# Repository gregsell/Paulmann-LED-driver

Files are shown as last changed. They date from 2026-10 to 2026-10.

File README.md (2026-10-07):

# Dimmable LED driver analysis
The situation: I bought several LED spots called "Nova Plus" by the company Paulmann.   
(https://de.paulmann.com/p/led-modul-einbauleuchte-nova-plus-coin-rund-50mm-coin-6w-470lm-230v-dimmbar-2700k-satin/93078)

The lights are rated for 6W and intended for use with a dimmer, but many of them stopped working. Time for investigations.

## Driver PCB

Main goal: create schematic from scratch and understand how things work. Ideally fix the broken units.  
The IC is a `iW3688` by Renesas. It supports leading and trailing edge dimming. The `-01` variant found here supports 230VAC input with up to 14 W output power.  
(https://www.renesas.com/en/document/prb/iw3688-product-summary?r=1543101)

For most defective units the only apparent damage was the blown fusible resistor. All the other simple components seemed fine.  
The state of the main IC could not be assessed due to lack of information and tooling.

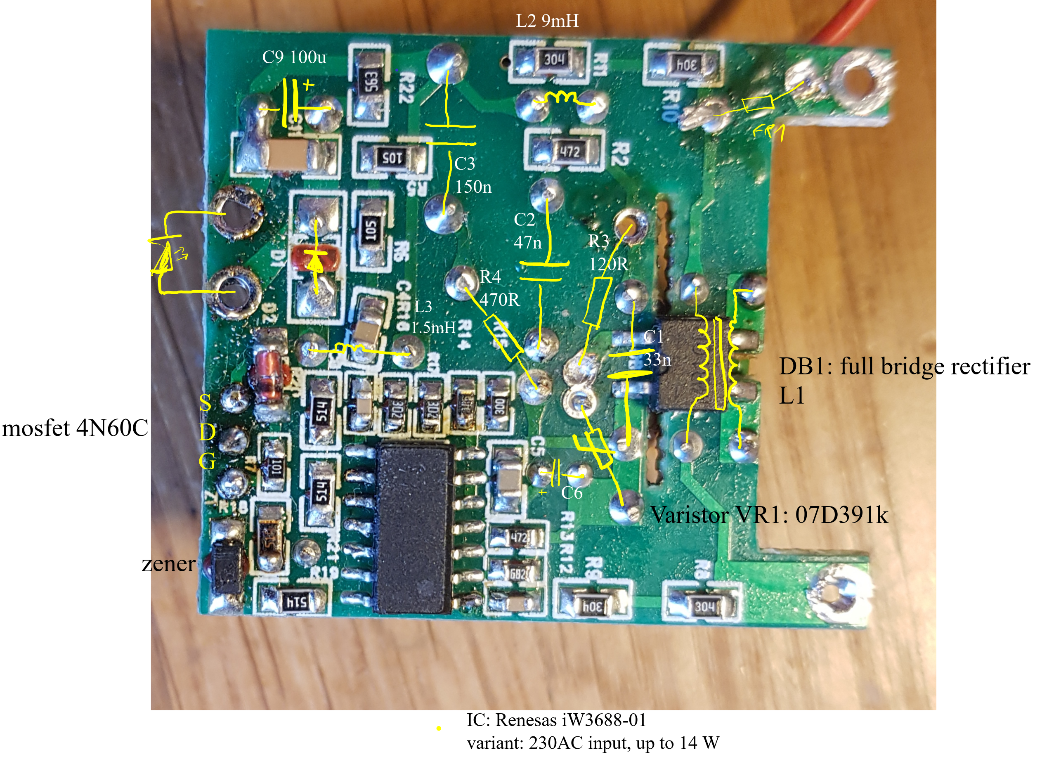
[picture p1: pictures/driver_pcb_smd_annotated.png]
driver pcb smd annotated

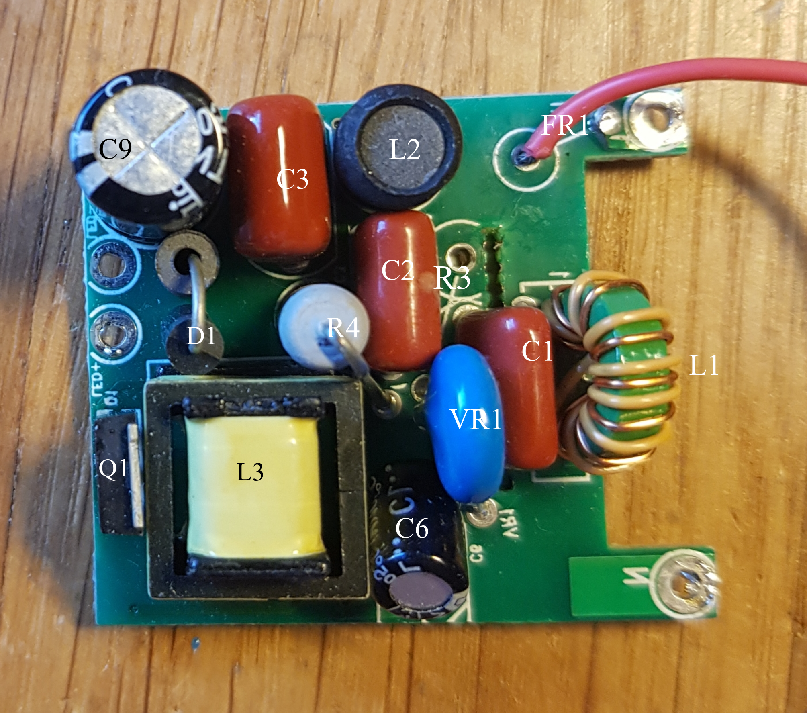
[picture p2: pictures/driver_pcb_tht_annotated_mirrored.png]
driver pcb tht annotated
  
(mirrored)

### Schematic

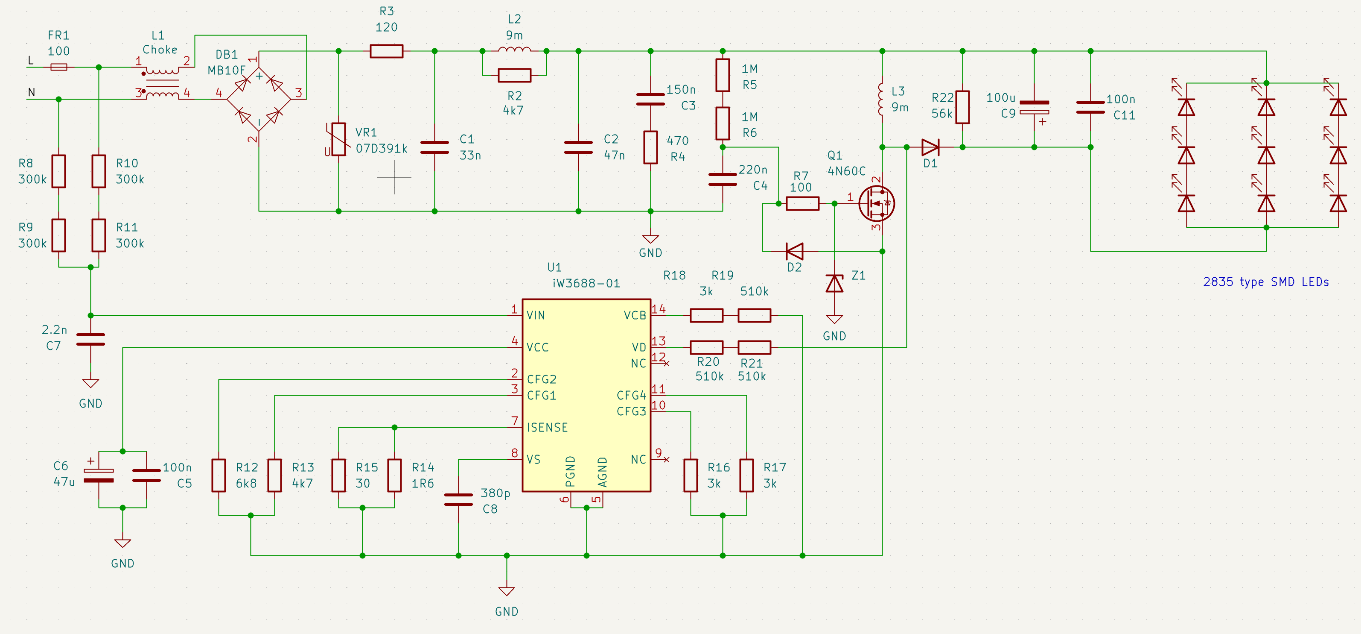
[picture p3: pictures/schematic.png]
reverse engineered schematic


The schematic turned out to be very similar to the example in the production summary.

## Failure analysis
TBD  

## LED PCB

The seperate pcb with the actual LEDs contains 15 SMD LEDs in total. Five strings of each 3 LEDs in series.  
The package form is 2835 (2,8 x 3,5mm).
While 'usual' white LEDs work in the ~3V range these turn on at about 15 V.

None of the defective units had failed LEDs. Assuming a single SMD LED failed, the two remaining strings will be loaded 50 % more and soon overheat. This is due to the constant-current driving mechanism of LED drivers. 

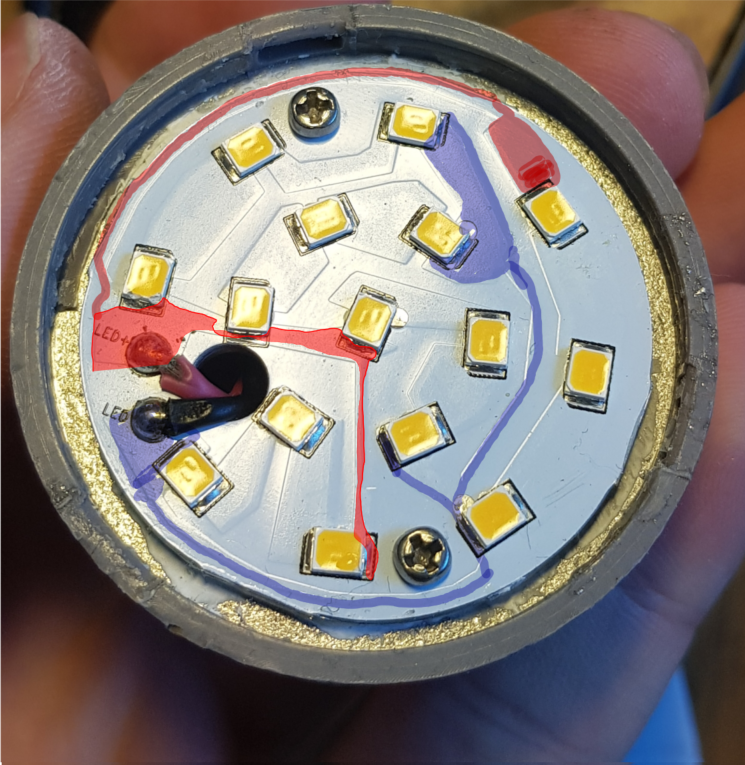
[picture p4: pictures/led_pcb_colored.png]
led pcb colored traces


## Extending LED lifetime

It is common for LED drivers to 'push' too much current through the LEDs. As a result they get hot and the lifetime shortens. For many (cheap) lights this is a very common failure mode.  
In this case though the LEDs are still working. Nevertheless, investigating how to modify the drivers behaviour is at least interesting.

The used IC has several resistors for configuring behaviour, one of them ($R_{14} || R_{15}$) is used to set the current to power the LEDs ($I_{LED}$) 

In the table below are measurements comparing the stock configuration with a modified one.
- $U_{LED}$:    Average DC voltage measured across LEDs
- $I_{LED}$:    Average DC current flowing through LEDs
- $R_{sense}$:  Resistor for defining $I_{LED}$. It is consists of $R_{14}$ and $R_{15}$ in parallel

| | $U_{LED}$ [V] |  $I_{LED}$ [mA] | $R_{sense}$ [Ohm] |
| --- | --- | --- | --- |
| stock | 52 | 101 | 1,5 |
| mod | 50 | 50 | 3,1 |

Therefore the correlation  $I_{LED} \propto 1/R_{sense} $  holds. This is common for LED drivers.

## Possible further investigations
Unfortunately a full datasheet of the `iW3688` IC by Renesas is not available, only [this production summary](https://www.renesas.com/en/document/prb/iw3688-product-summary?r=1543101). Thus further analysis is hardly possible. 

### Precise measurement of $U_{LED}$

All measurements above were done with a simple digital multimeter (DMM).  
Probing the output voltage relative to earth with an oscilloscope led to the following graph:    

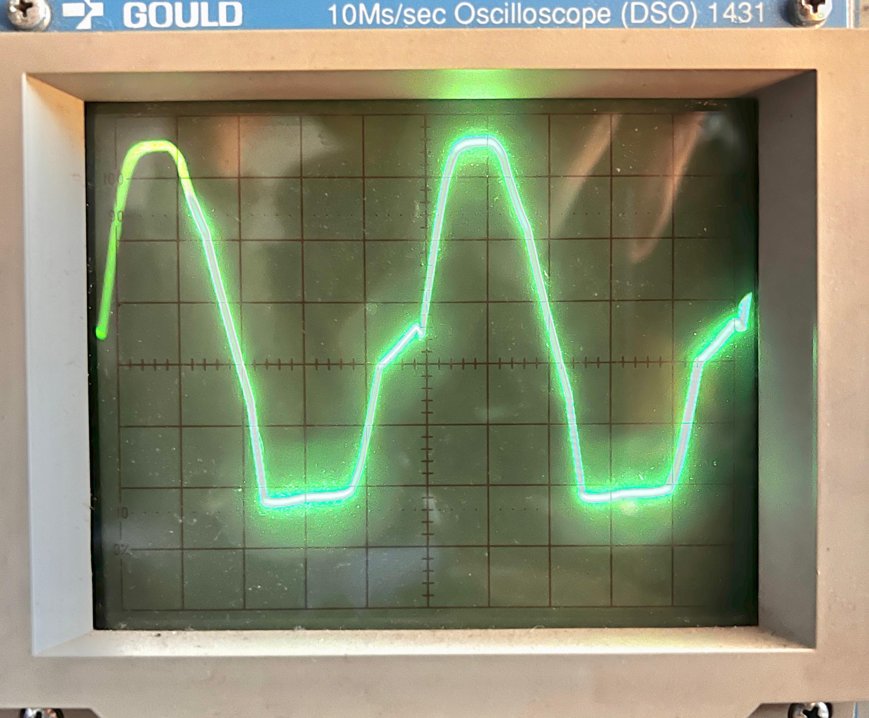
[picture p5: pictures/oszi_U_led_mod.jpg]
U_led on oscilloscope (R_sense modified)


Zero volts reference is at the bottom of the screen.
The units are:
- 20 V / div. vertically
- 20 ms / div. horizontally  

#### Observations:
The base frequency is 50 Hz, although for a full bridge rectifier it should be double that.

#### Why this measurement was not very useful:
Neither do I own an isolation transformer nor differential probes. Thus the point of reference (neg. LED terminal) (might be?) swinging as well. *I think* this could be solved by using a second probe (which I do not have) and subtracting the signals.

Working on mains voltage with an unisolated powersupply is dangerous anyway. Don't do it.

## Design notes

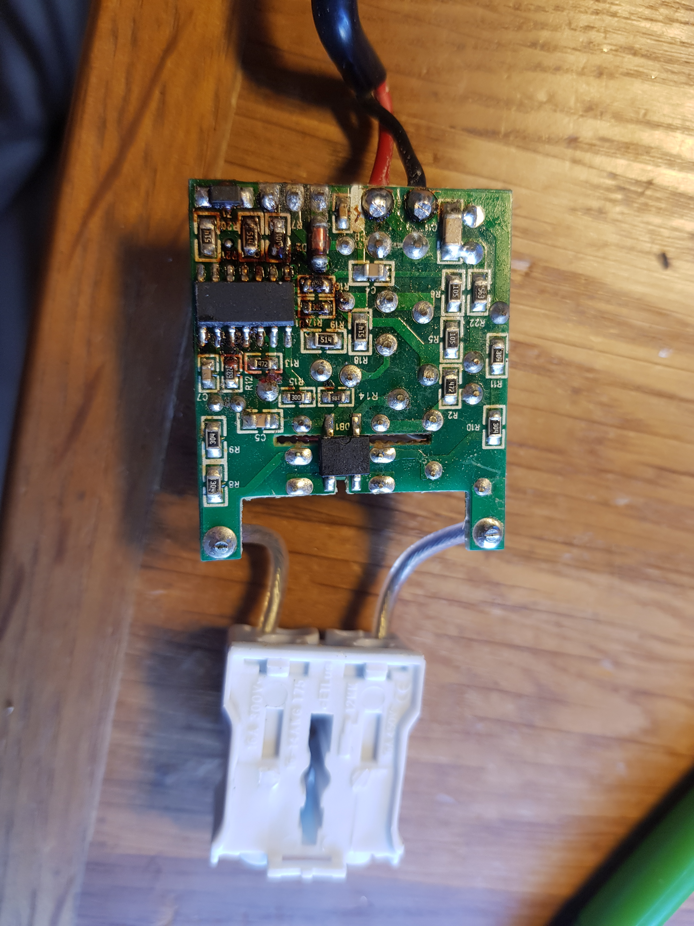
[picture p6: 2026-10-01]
pictures/brown_pcb.jpg

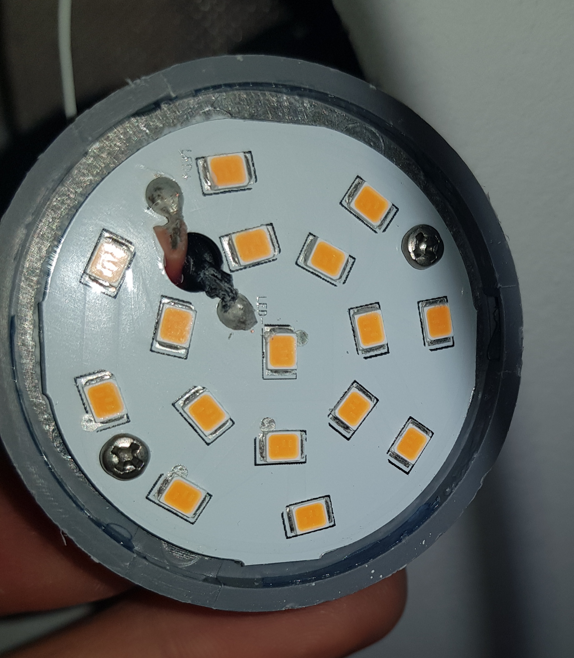
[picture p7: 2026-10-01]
pictures/led_pcb_16.jpg

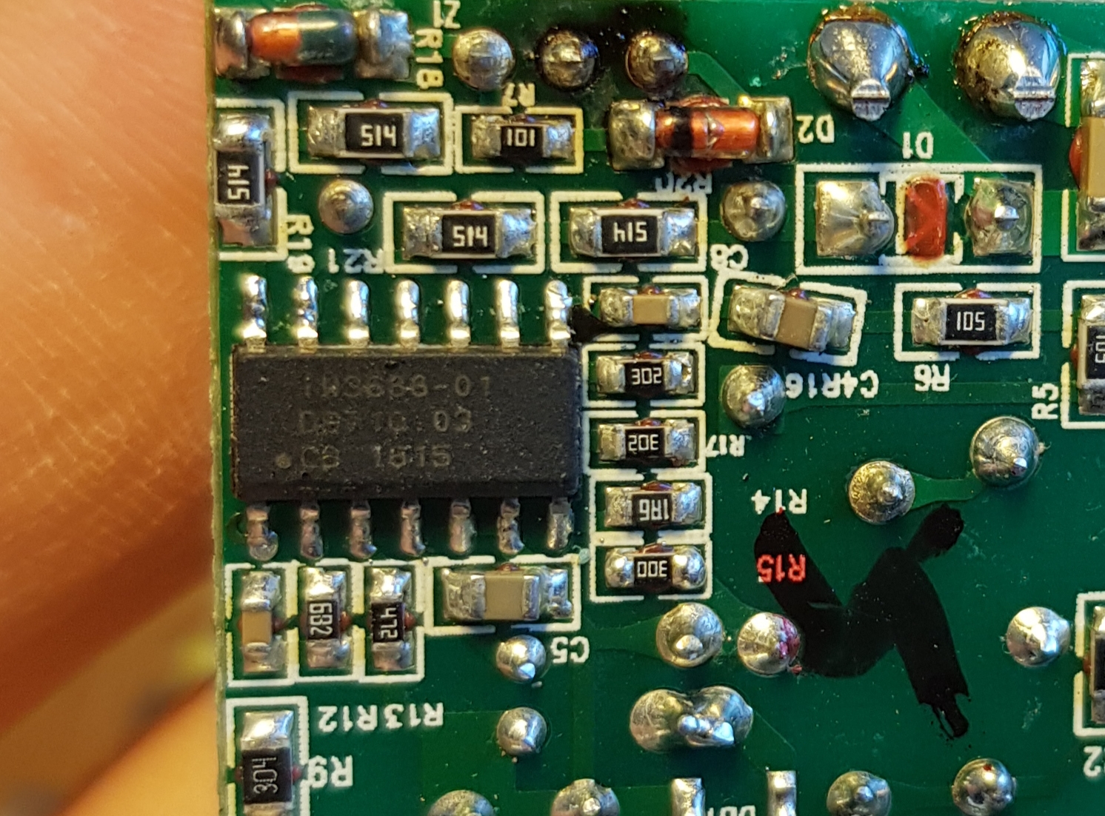
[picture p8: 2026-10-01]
pictures/IC_name.jpg

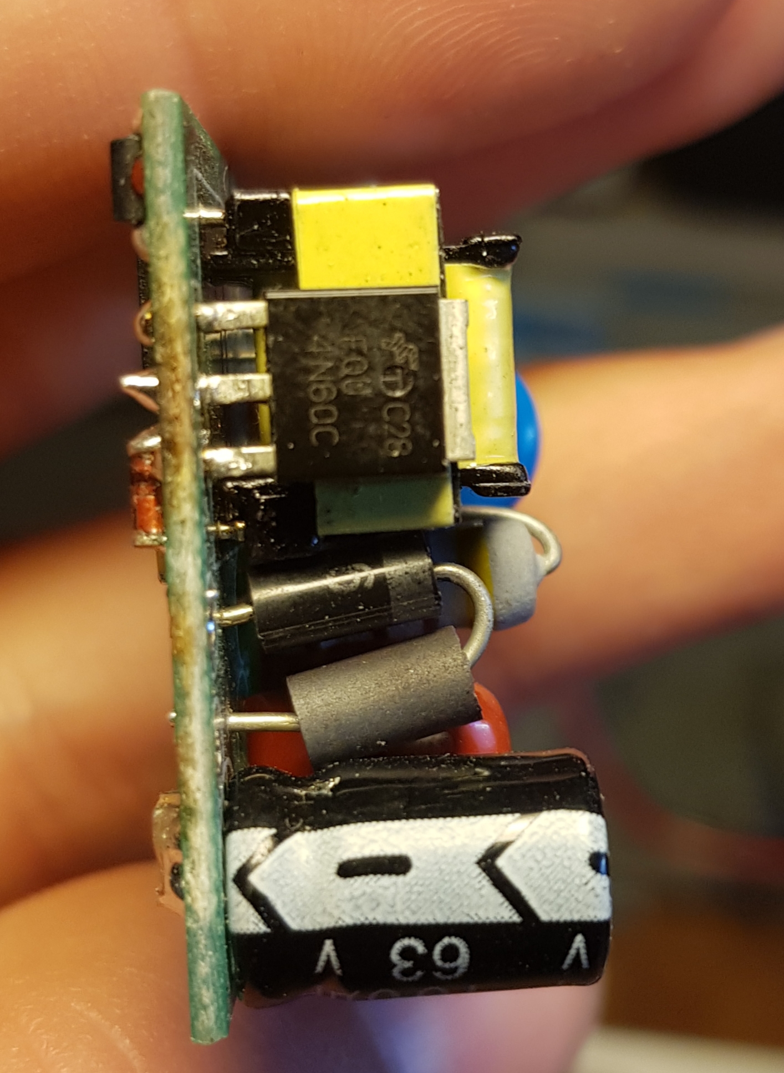
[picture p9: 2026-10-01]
pictures/mosfet_side.jpg

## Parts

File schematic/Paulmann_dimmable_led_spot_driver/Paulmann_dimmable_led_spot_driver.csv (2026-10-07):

Reference | Qty | Value
C1 | 1 | 33n
C2 | 1 | 47n
C3 | 1 | 150n
C4 | 1 | 220n
C5,C11 | 2 | 100n
C6 | 1 | 47u
C7 | 1 | 2.2n
C8 | 1 | 380p
C9 | 1 | 100u
D1,D2 | 2 | 1N4001
DB1 | 1 | MB10F
FR1,R7 | 2 | 100
L1 | 1 | Choke
L2,L3 | 2 | 9m
LED1,LED2,LED3,LED4,LED5,LED6,LED7,LED8,LED9 | 9 | LED
Q1 | 1 | 4N60C
R2,R13 | 2 | 4k7
R3 | 1 | 120
R4 | 1 | 470
R5,R6 | 2 | 1M
R8,R9,R10,R11 | 4 | 300k
R12 | 1 | 6k8
R14 | 1 | 1R6
R15 | 1 | 30
R16,R17,R18 | 3 | 3k
R19,R20,R21 | 3 | 510k
R22 | 1 | 56k
U1 | 1 | iW3688-01
VR1 | 1 | 07D391k
Z1 | 1 | 19V

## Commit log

2026-10-01 THT values + led pcb retrace
2026-10-07 notes on schematic and pcb, images
    [Paulmann_dimmable_led_spot_driver.csv, Paulmann_dimmable_led_spot_driver.kicad_sch]
